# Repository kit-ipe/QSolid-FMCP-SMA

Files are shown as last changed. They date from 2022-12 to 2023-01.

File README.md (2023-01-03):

# FMC+ SMA

## Cloning the repository
- Libraries used in the project are in this other [cern repository](https://gitlab.cern.ch/p2-xware/hardware/kicad-pcbs/kit-kicad-library) or [kit repository](https://git.scc.kit.edu/cms-tt/hardware/kicad-pcbs/kit-kicad-library) and need to be linked using an **Environment Variable** inside KiCad (Preferences -> Configure Paths... ->) right after opening the project
 
  `KICAD_USER_LIBRARY = /path/to/KIT_KiCad_Library`

## 3D Views

### Top

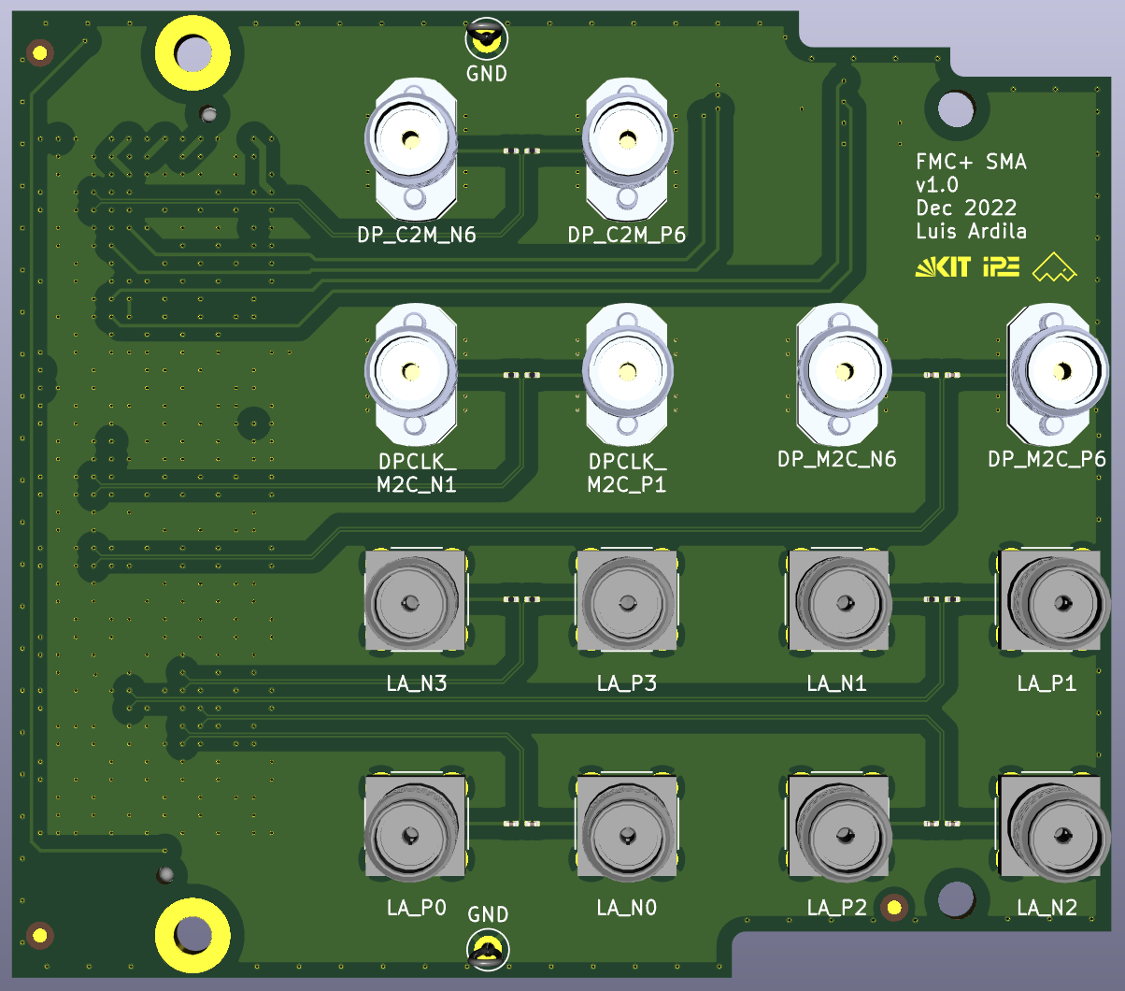
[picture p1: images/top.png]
Top View 3D


### Bottom

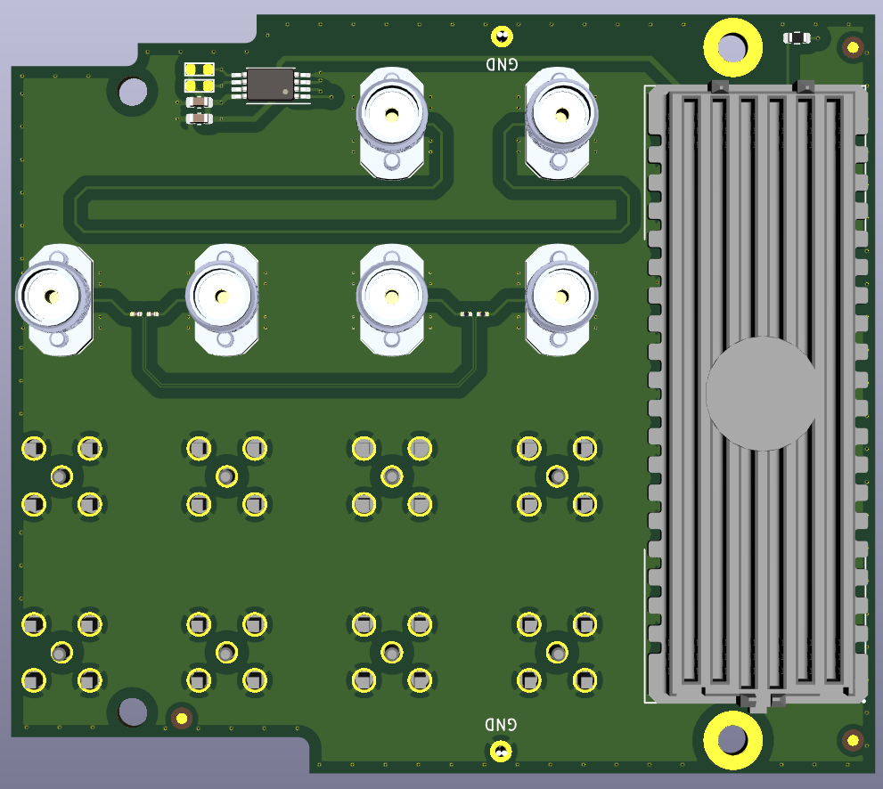
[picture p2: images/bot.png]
Bottom View 3D


## LICENSE

Copyright Luis Ardila, Marvin Fuchs, Robert Gartmann, Lukas Scheller 2023.

This source describes Open Hardware and is licensed under the CERN-OHL-P v2
You may redistribute and modify this documentation and make products
using it under the terms of the CERN-OHL-P v2 [https:/cern.ch/cern-ohl](https:/cern.ch/cern-ohl).
This documentation is distributed WITHOUT ANY EXPRESS OR IMPLIED
WARRANTY, INCLUDING OF MERCHANTABILITY, SATISFACTORY QUALITY
AND FITNESS FOR A PARTICULAR PURPOSE. Please see the CERN-OHL-P v2
for applicable conditions.

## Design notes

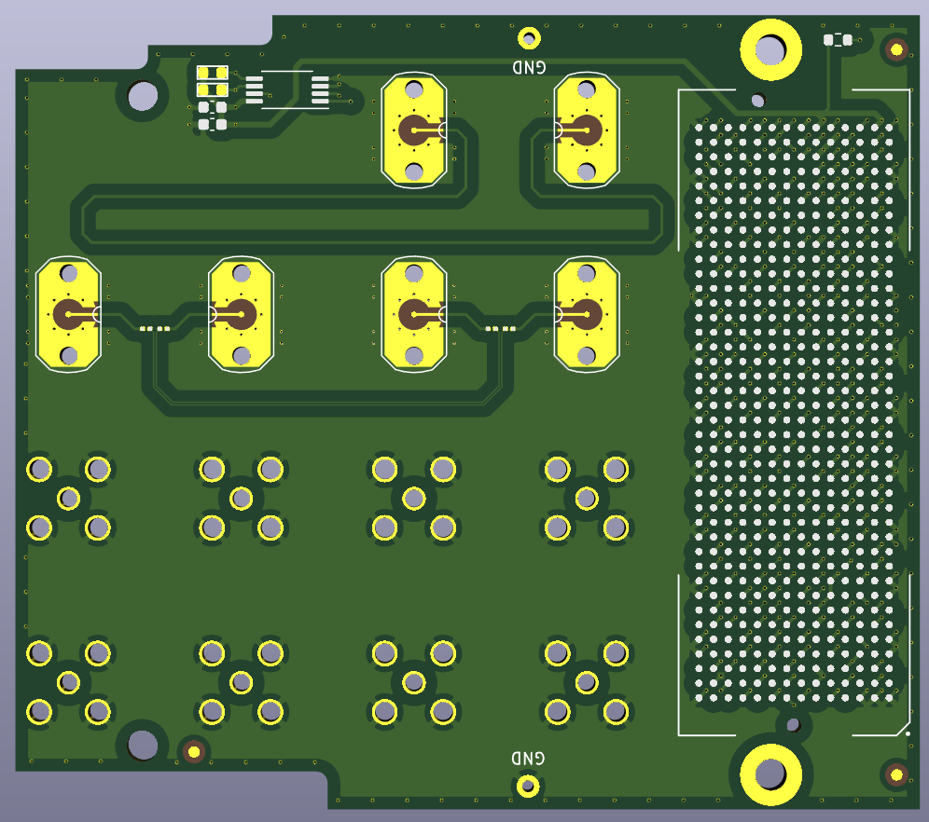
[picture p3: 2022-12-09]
images/bot-pcb.png

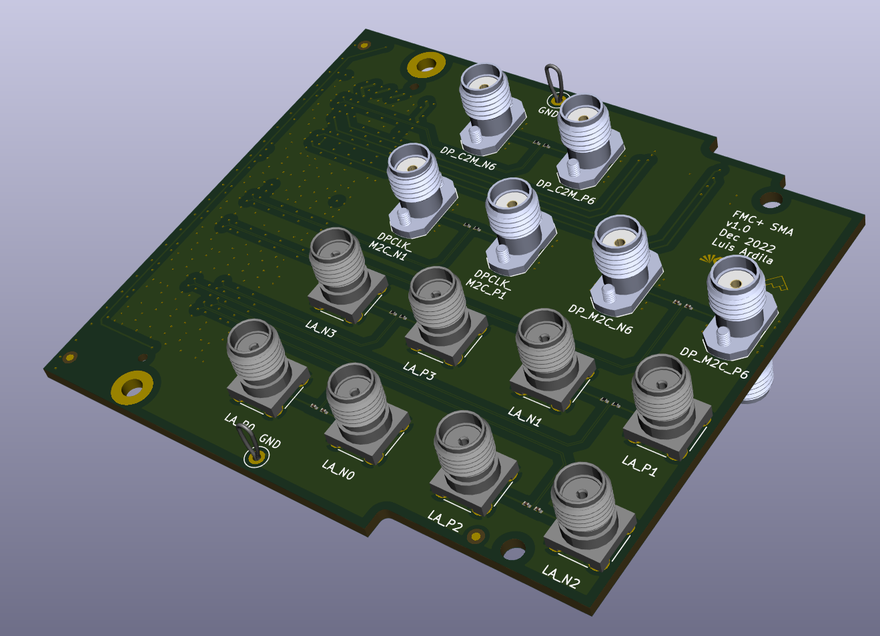
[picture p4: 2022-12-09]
images/iso.png

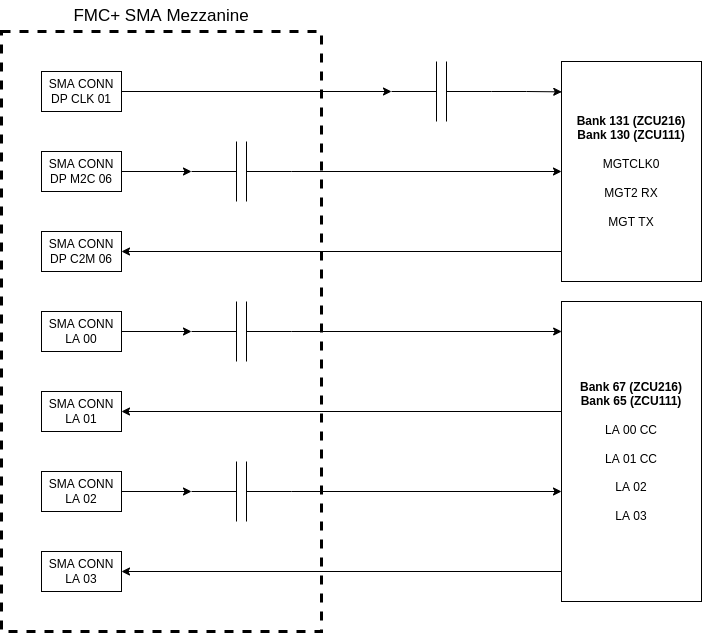
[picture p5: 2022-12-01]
images/fmcp_sma_block_diagram.drawio.png

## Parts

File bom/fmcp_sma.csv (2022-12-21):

refs | qty | Value | Footprint | Datasheet | rs# | info | stock | DNP | manf | manf#
C101 C102 C103 C104 C105 C106 C107 C108 | 8 | 0.1uF | Capacitor_SMD:C_0201_0603Metric | ~ | 185-1596 | 0201, 25V, X5R, 10% | Luis
C109 | 1 | 1uF | Capacitor_SMD:C_0603_1608Metric | ~ |  | 0402, 16V | AVT-IPE
C118 | 1 | 0.1uF | Capacitor_SMD:C_0603_1608Metric | ~ |  | 0402, 16V | AVT-IPE
FID101 FID102 FID103 FID104 FID105 FID106 | 6 | Fiducial | Fiducial:Fiducial_1mm_Mask2mm | ~
G101 | 1 | LA_LOGO | KIT_Graphic:LA_LOGO_MASK_NoName
G102 | 1 | KIT_LOGO | KIT_Graphic:KIT_LOGO_MASK_4.1x1.6mm
H102 H104 | 2 | M2.5 | MountingHole:MountingHole_2.7mm_M2.5 | ~
H101 H103 | 2 | M2.5_Pad | MountingHole:MountingHole_2.7mm_M2.5_Pad | ~
J101 J102 J104 J105 J106 J107 J116 J117 J118 J119 J120 J121 | 12 | Conn_Coaxial | KIT_Connector:SF2921-61345-1S | ~
J103 | 1 | FMCP_VITA57.4 | KIT_Connector:FMC_SEAM_ASP_184330_BGA-560_40x14_55.778x19.76mm | http://suddendocs.samtec.com/prints/asp-188588-01-mkt.pdf
J108 J109 J110 J111 J112 J113 J114 J115 | 8 | Conn_Coaxial | Connector_Coaxial:SMA_Amphenol_132134_Vertical | ~ | 253-0085 |  |  |  | Amphenol RF | 132134RP
J122 | 1 | Conn_01x03_Male | Connector_PinHeader_2.54mm:PinHeader_1x03_P2.54mm_Vertical | ~
R101 R102 R103 R104 R105 R106 R107 R108 R109 R112 | 10 | 0 | Resistor_SMD:R_0201_0603Metric | ~ |  |  | AVT-IPE
R110 R111 | 2 | 4.7k | KIT_Resistor_SMD:R_0603_1608Metric_DNP | ~ |  |  | AVT-IPE | DNP
R113 | 1 | 4.7k | Resistor_SMD:R_0603_1608Metric | ~ |  |  | AVT-IPE
TP101 TP102 TP104 TP105 | 4 | TestPoint | TestPoint:TestPoint_Loop_D2.50mm_Drill1.0mm | ~ | 262-2034
U101 | 1 | M24C02-FDW | Package_SO:TSSOP-8_4.4x3mm_P0.65mm | http://www.st.com/content/ccc/resource/technical/document/datasheet/b0/d8/50/40/5a/85/49/6f/DM00071904.pdf/files/DM00071904.pdf/jcr:content/translations/en.DM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 | 190-7599 |  |  |  | STMicroelectronics | M24C02-FDW6TP

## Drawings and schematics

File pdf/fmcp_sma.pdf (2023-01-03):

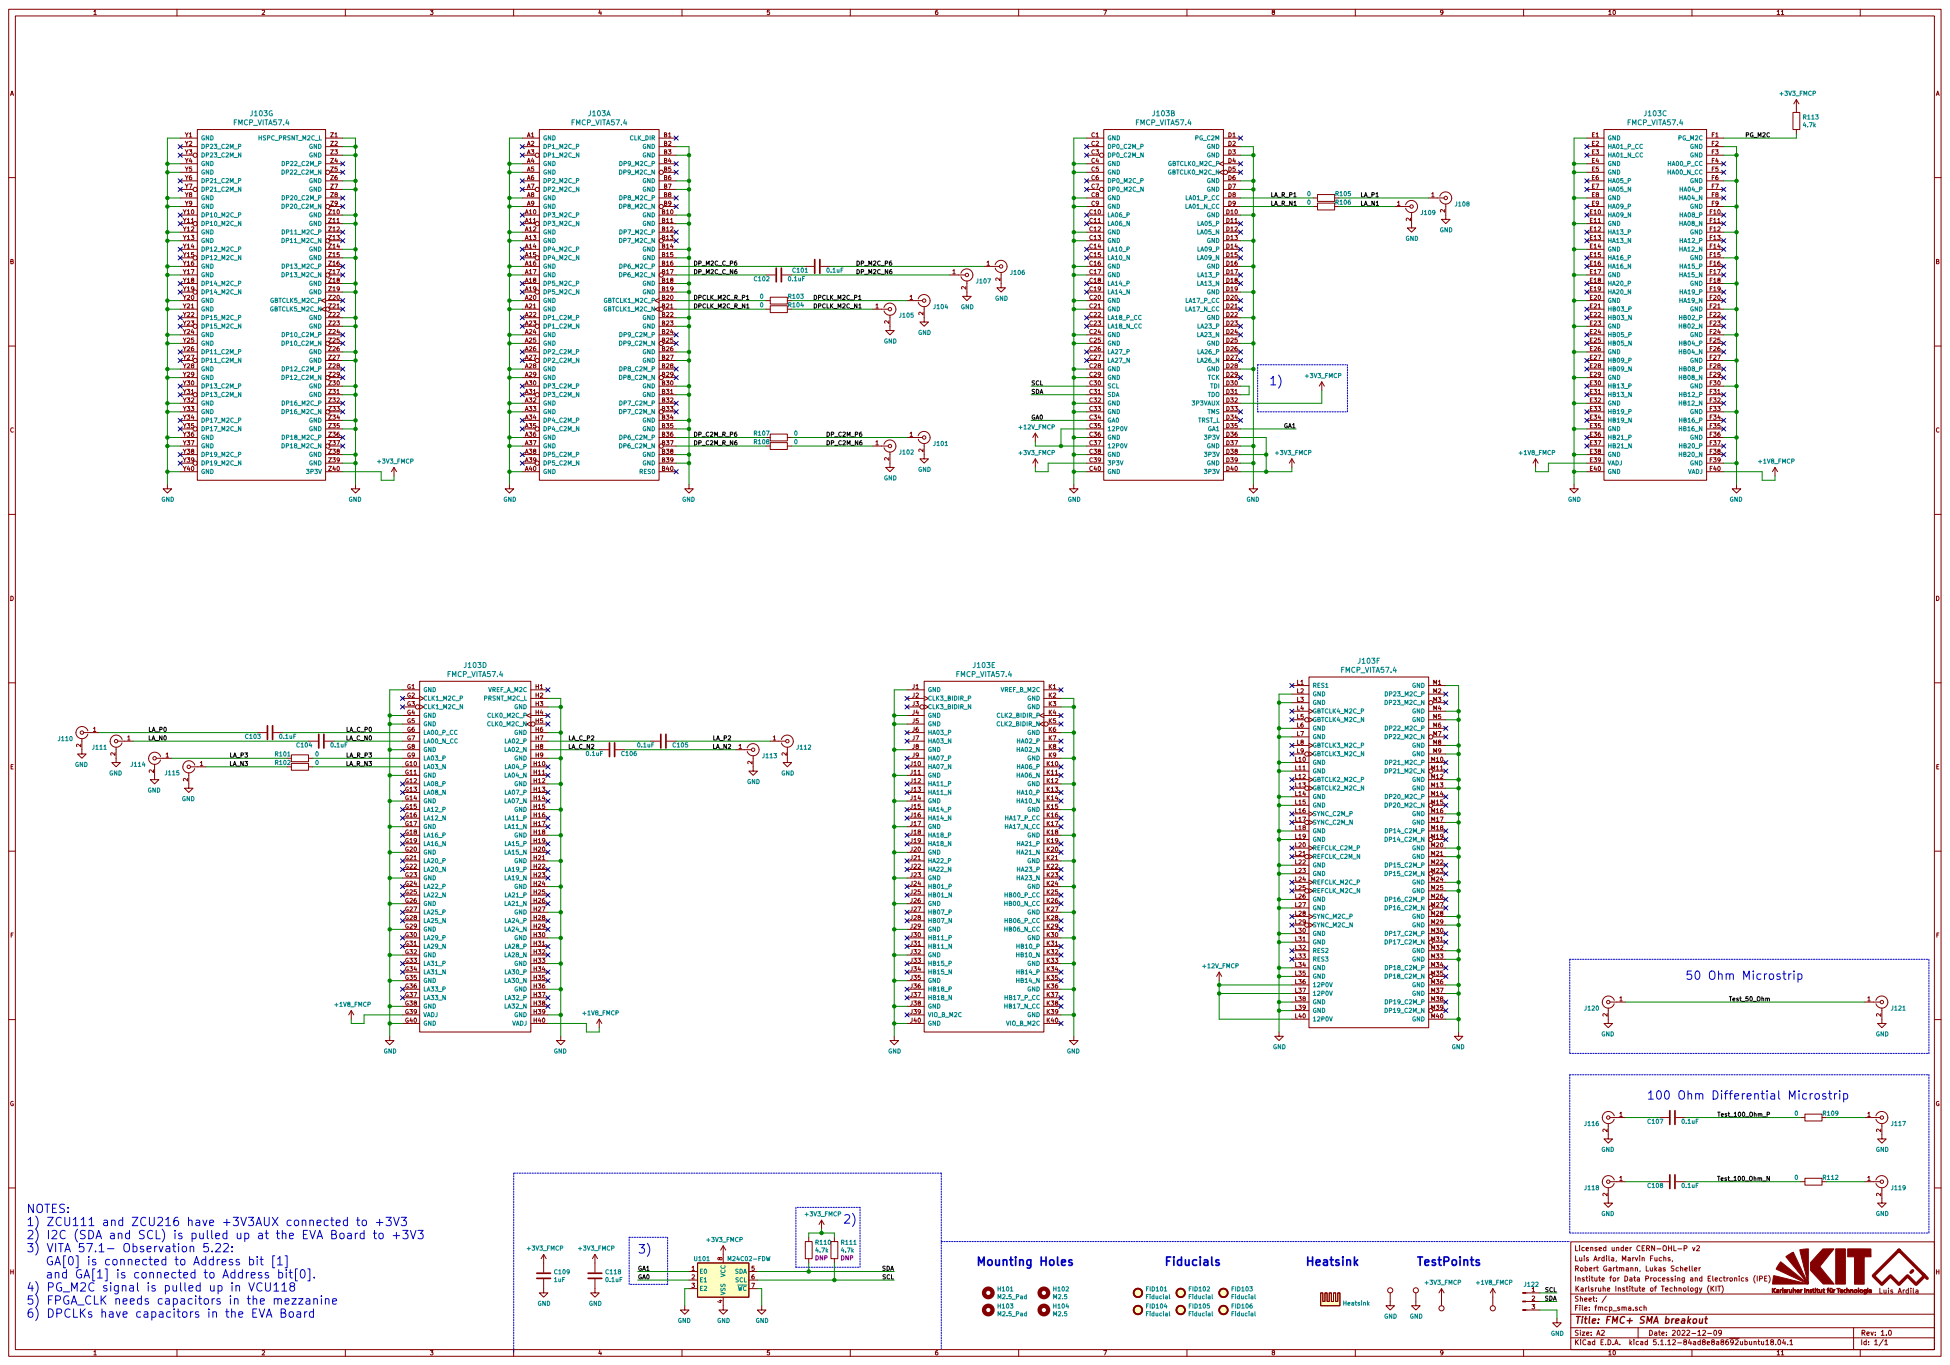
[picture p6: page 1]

NOTES:
1) ZCU111 and ZCU216 have +3V3AUX connected to +3V3
2) I2C (SDA and SCL) is pulled up at the EVA Board to +3V3
3) VITA 57.1- Observation 5.22:
GA[0] is connected to Address bit [1]
and GA[1] is connected to Address bit[0].
4) PG_M2C signal is pulled up in VCU118
5) FPGA_CLK needs capacitors in the mezzanine
6) DPCLKs have capacitors in the EVA Board

Luis Ardila, Marvin Fuchs, Licensed under CERN-OHL-P v2

4 SDA 5 SCL 6 WC 7 VCC

Robert Gartmann, Lukas Scheller
Institute for Data Processing and Electronics (IPE)
File: fmcp_sma.sch Sheet: / Karlsruhe Institute of Technology (KIT)

Id: 1/1 Title: FMC+ SMA breakout

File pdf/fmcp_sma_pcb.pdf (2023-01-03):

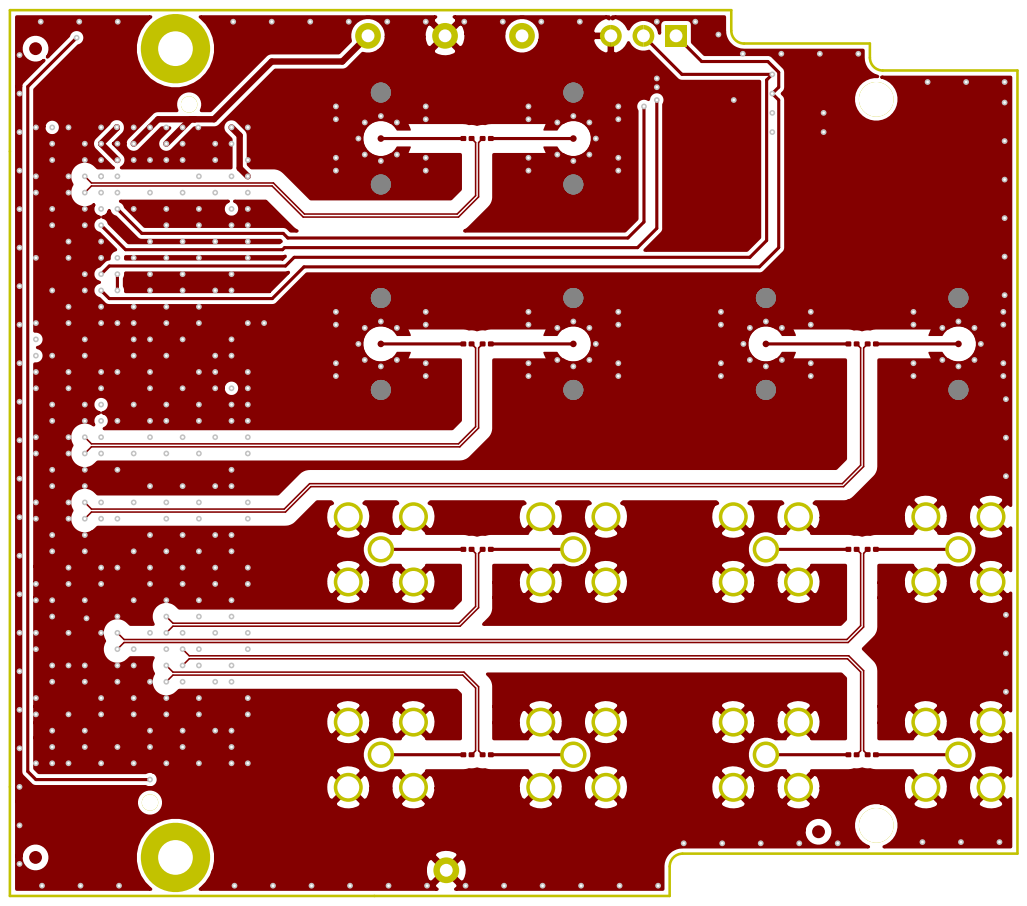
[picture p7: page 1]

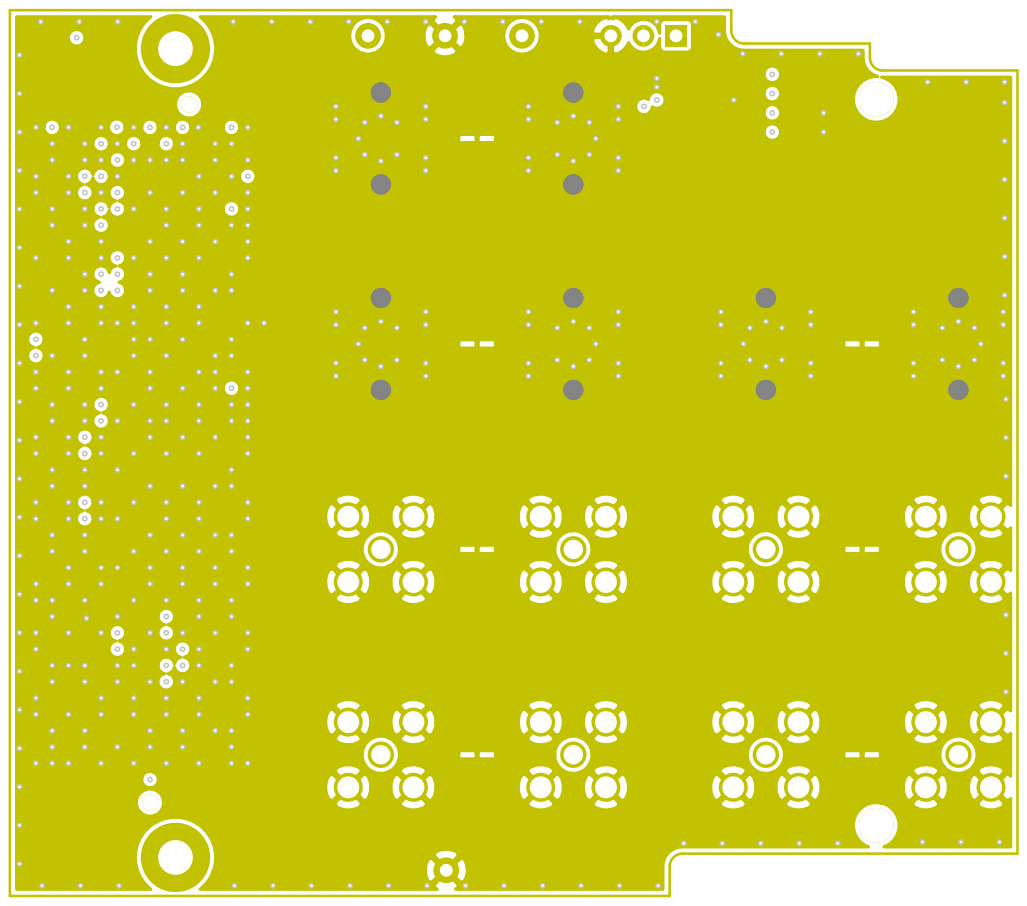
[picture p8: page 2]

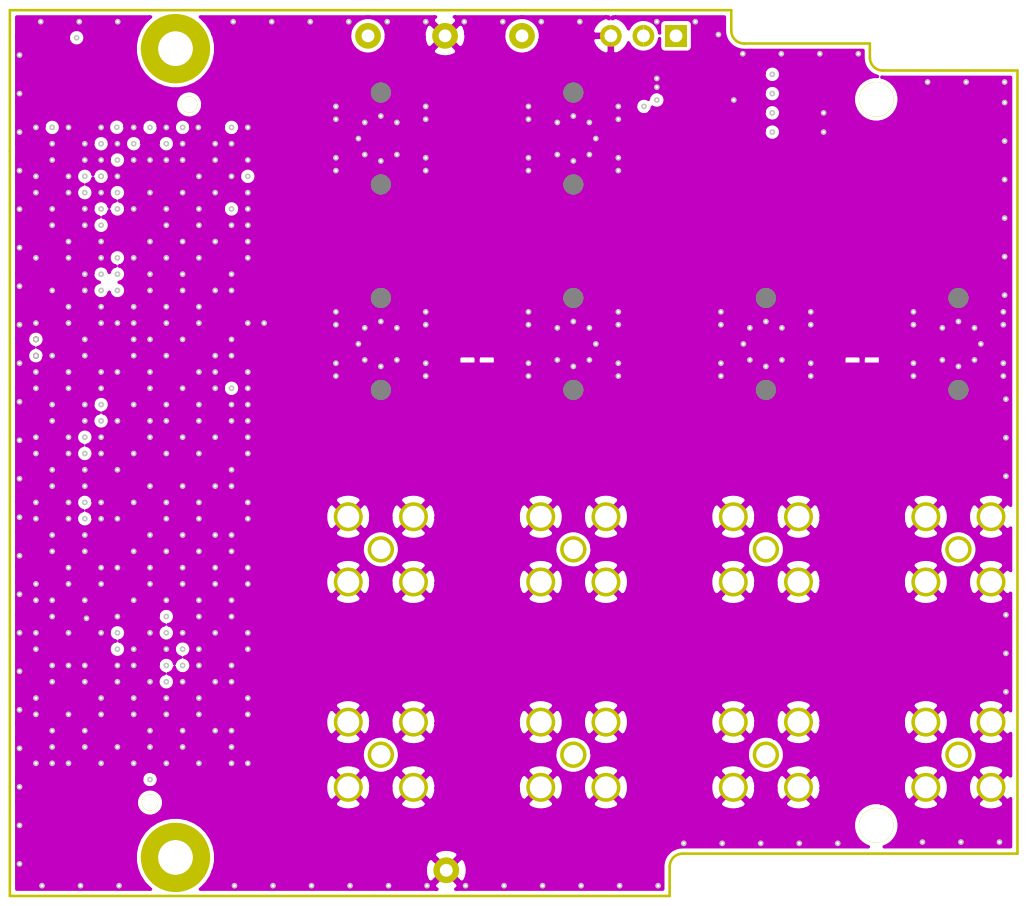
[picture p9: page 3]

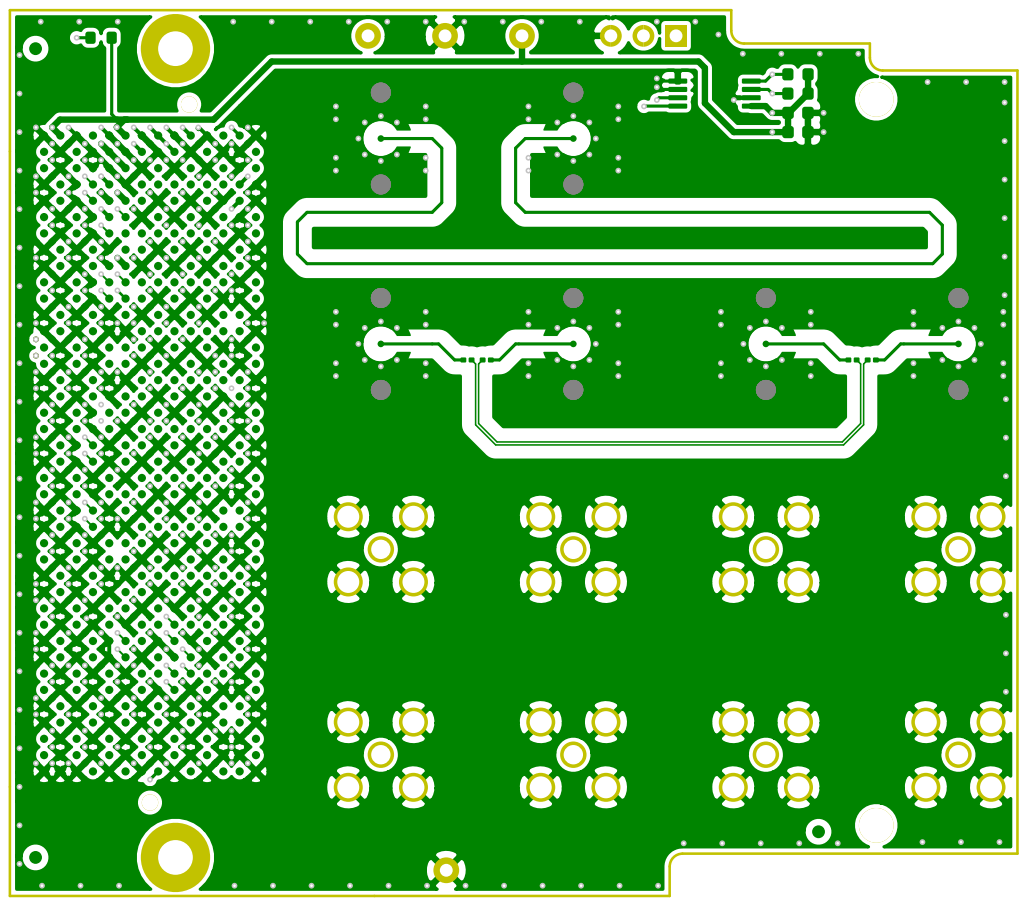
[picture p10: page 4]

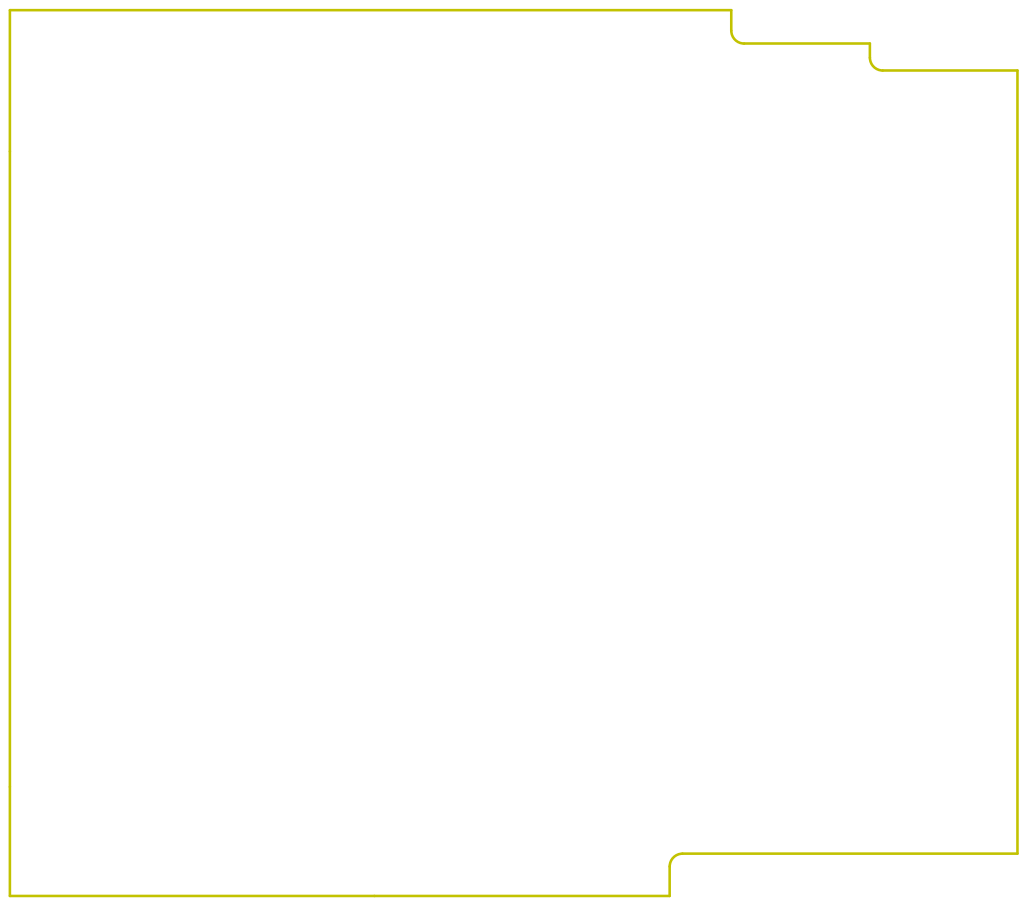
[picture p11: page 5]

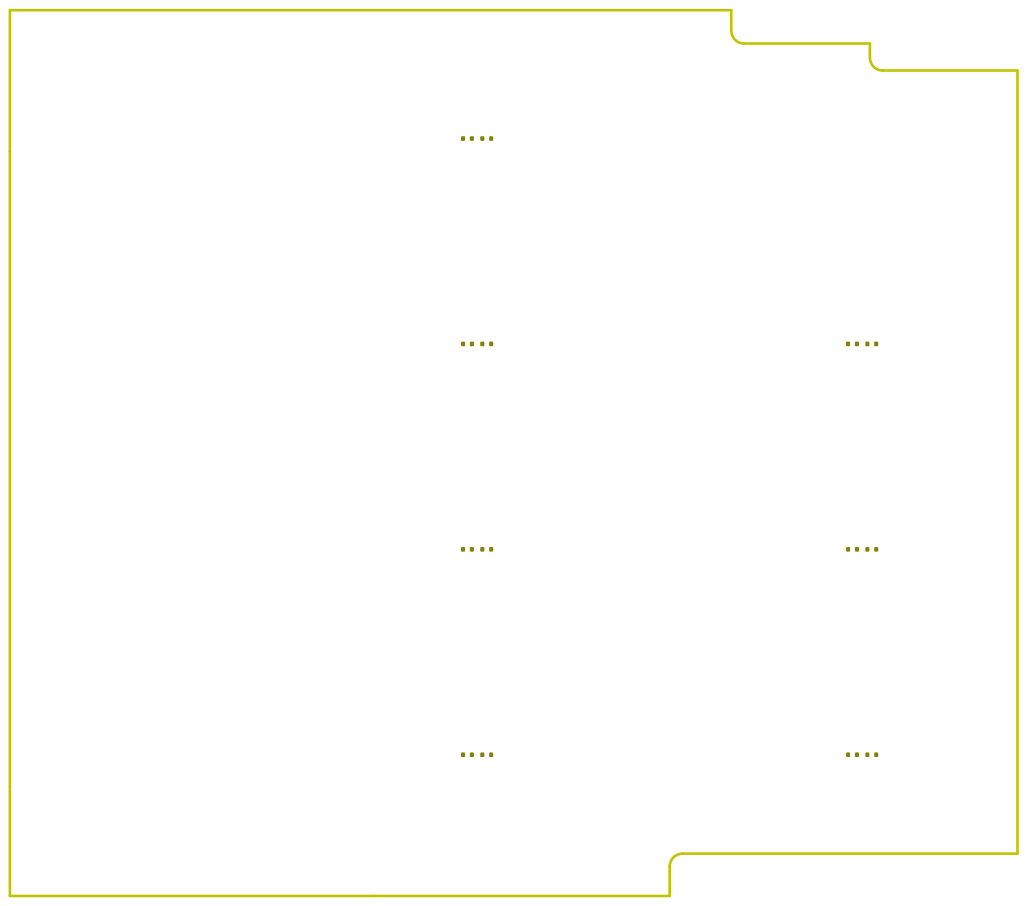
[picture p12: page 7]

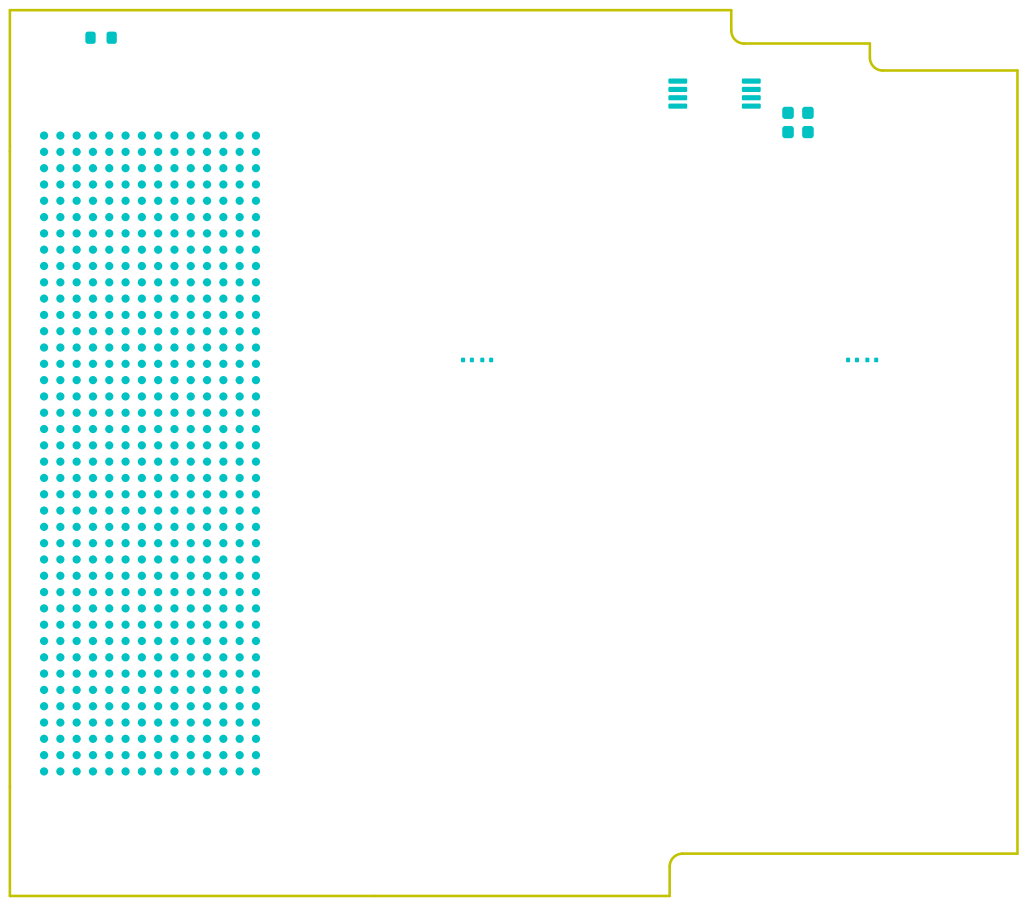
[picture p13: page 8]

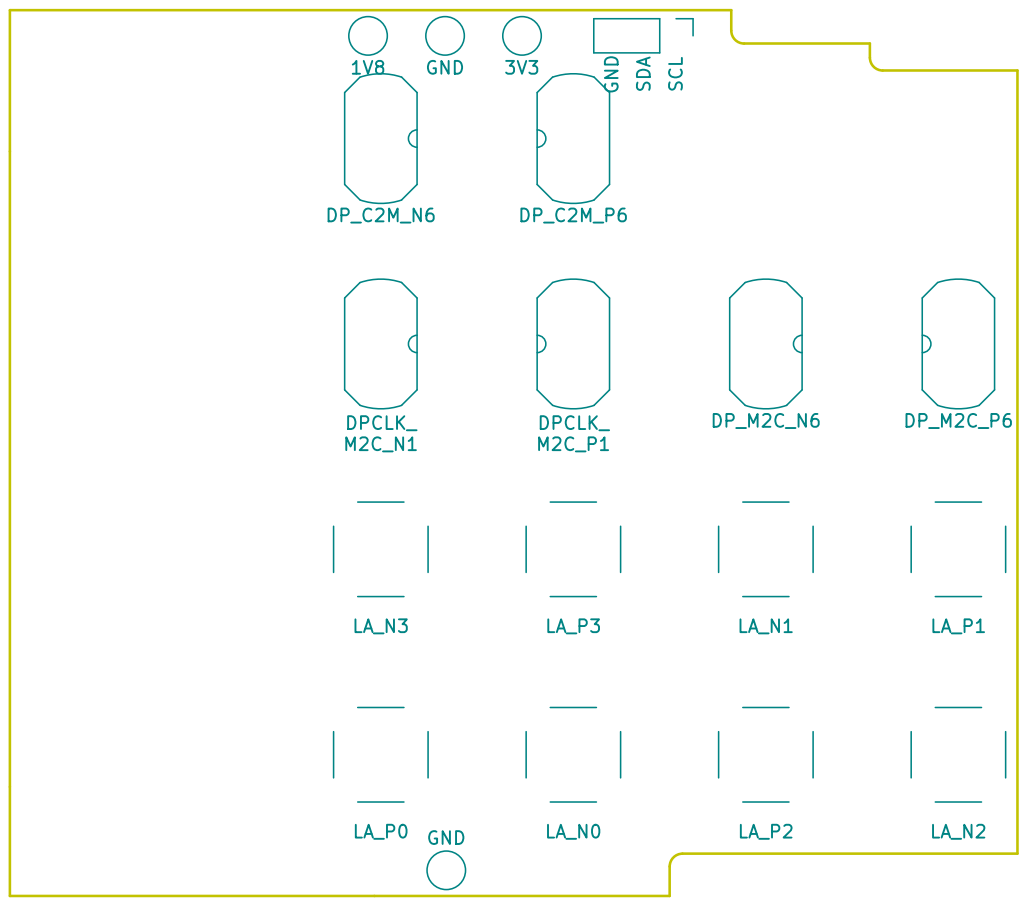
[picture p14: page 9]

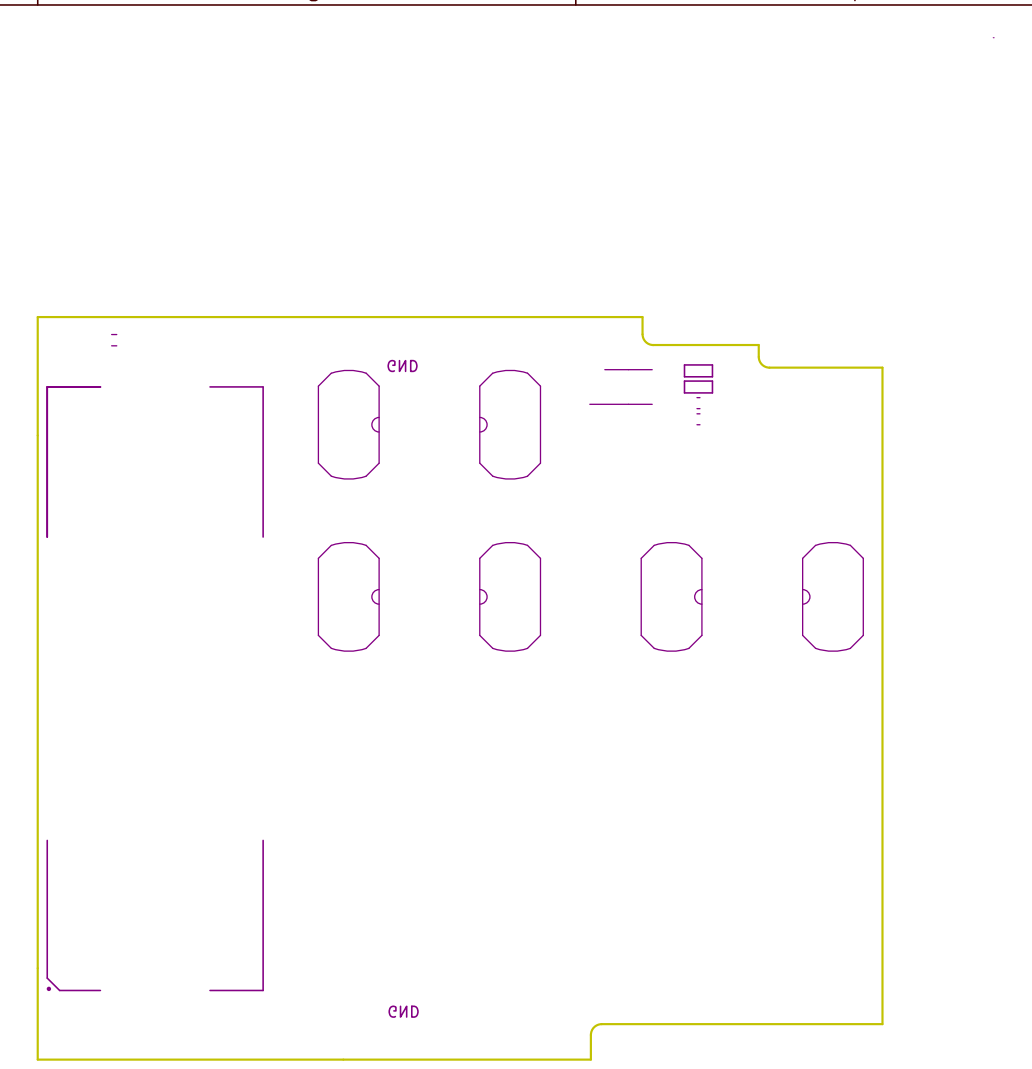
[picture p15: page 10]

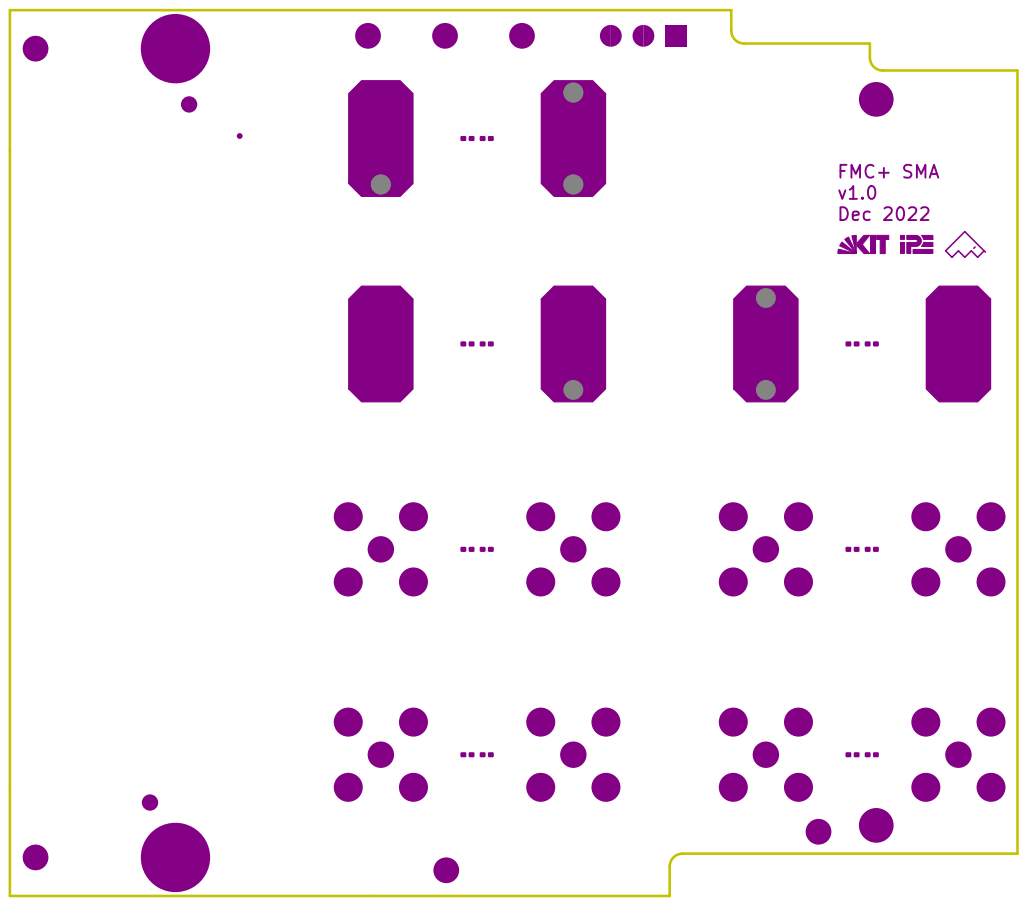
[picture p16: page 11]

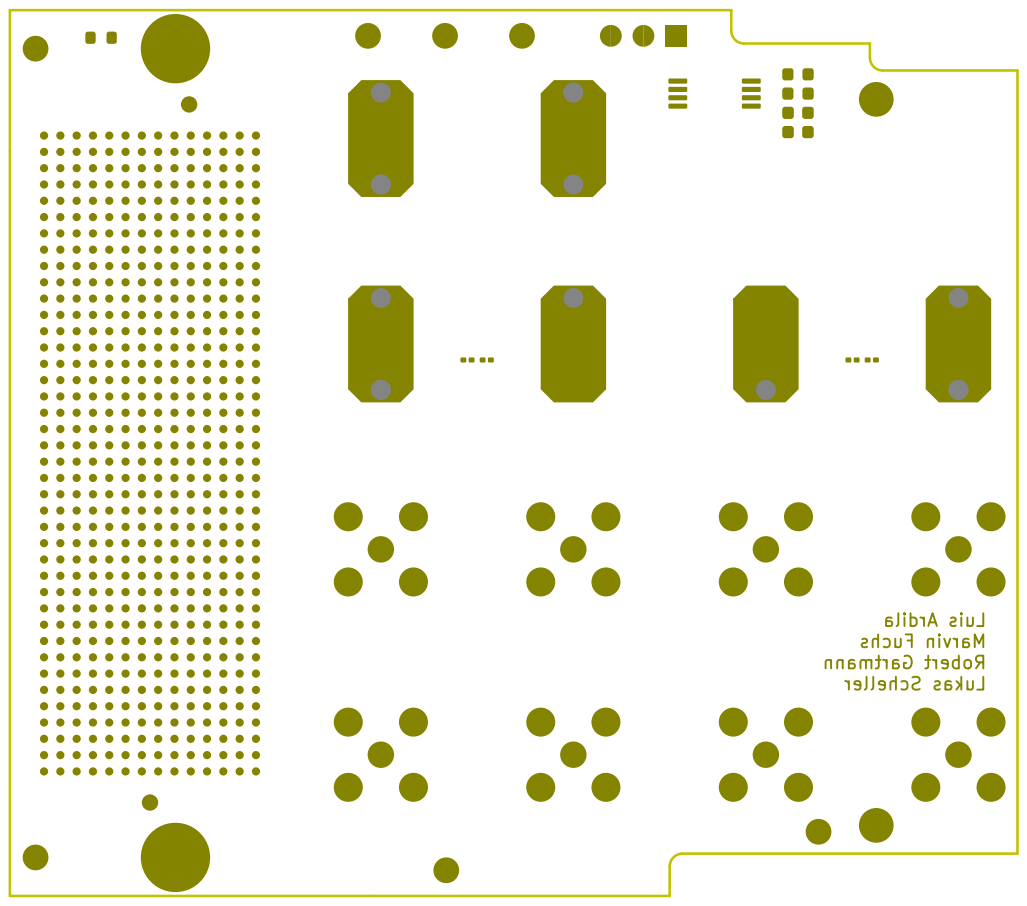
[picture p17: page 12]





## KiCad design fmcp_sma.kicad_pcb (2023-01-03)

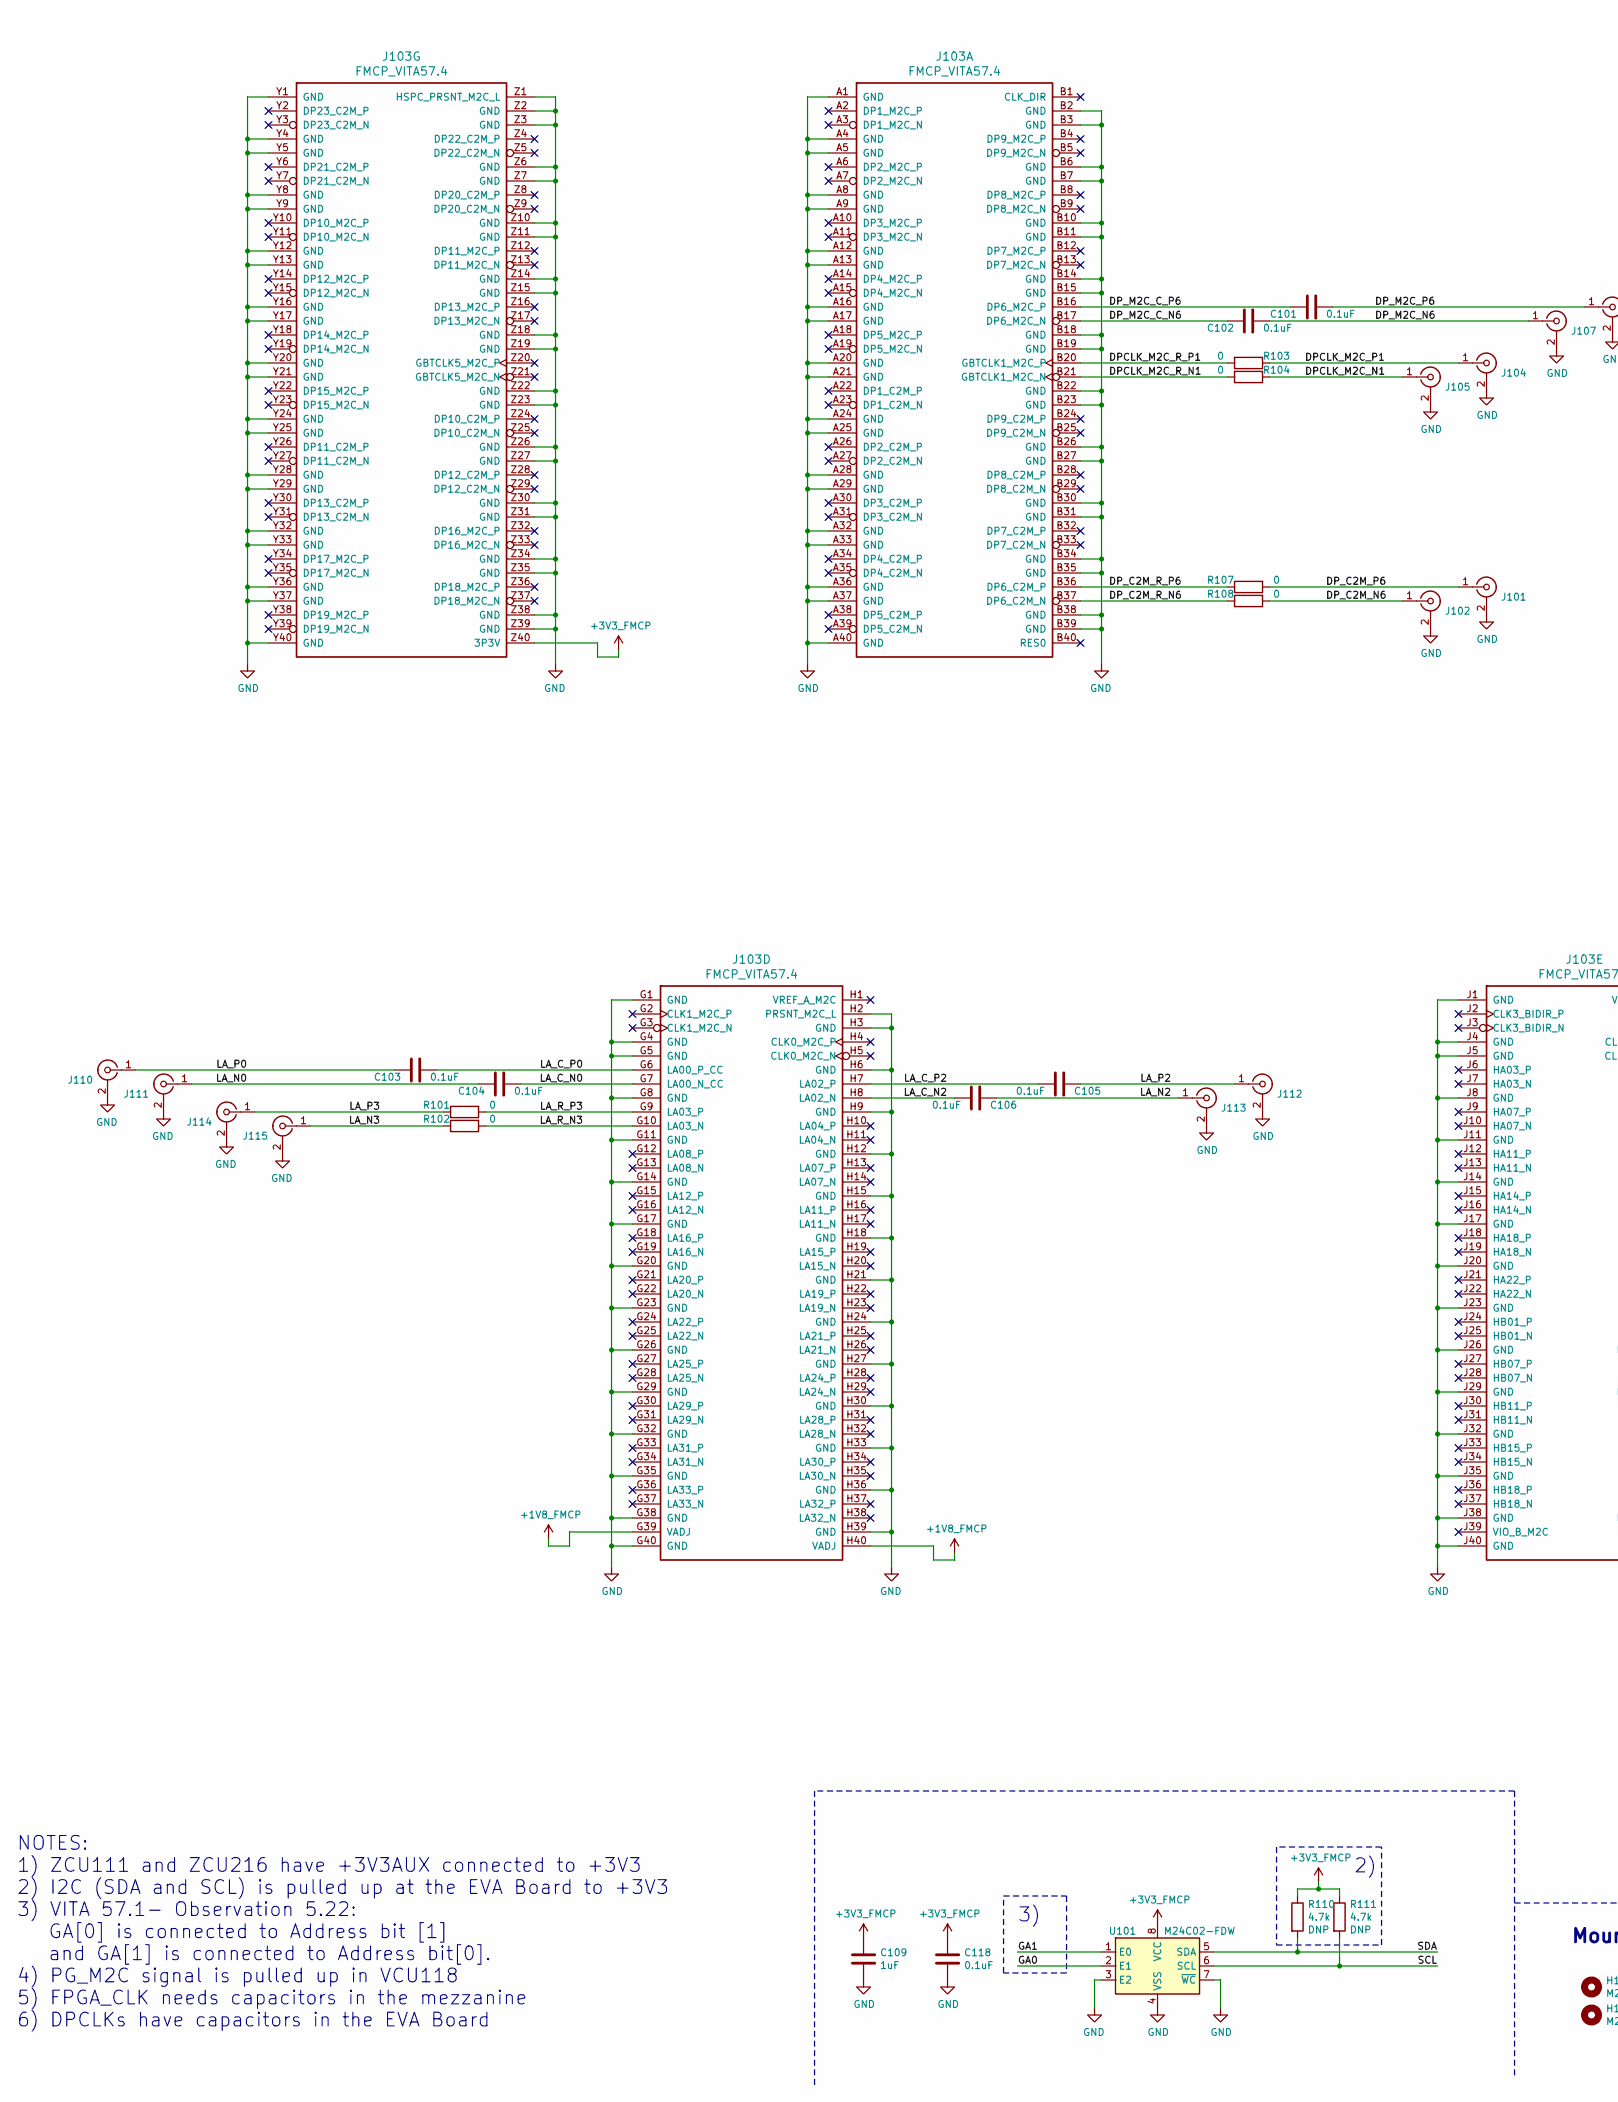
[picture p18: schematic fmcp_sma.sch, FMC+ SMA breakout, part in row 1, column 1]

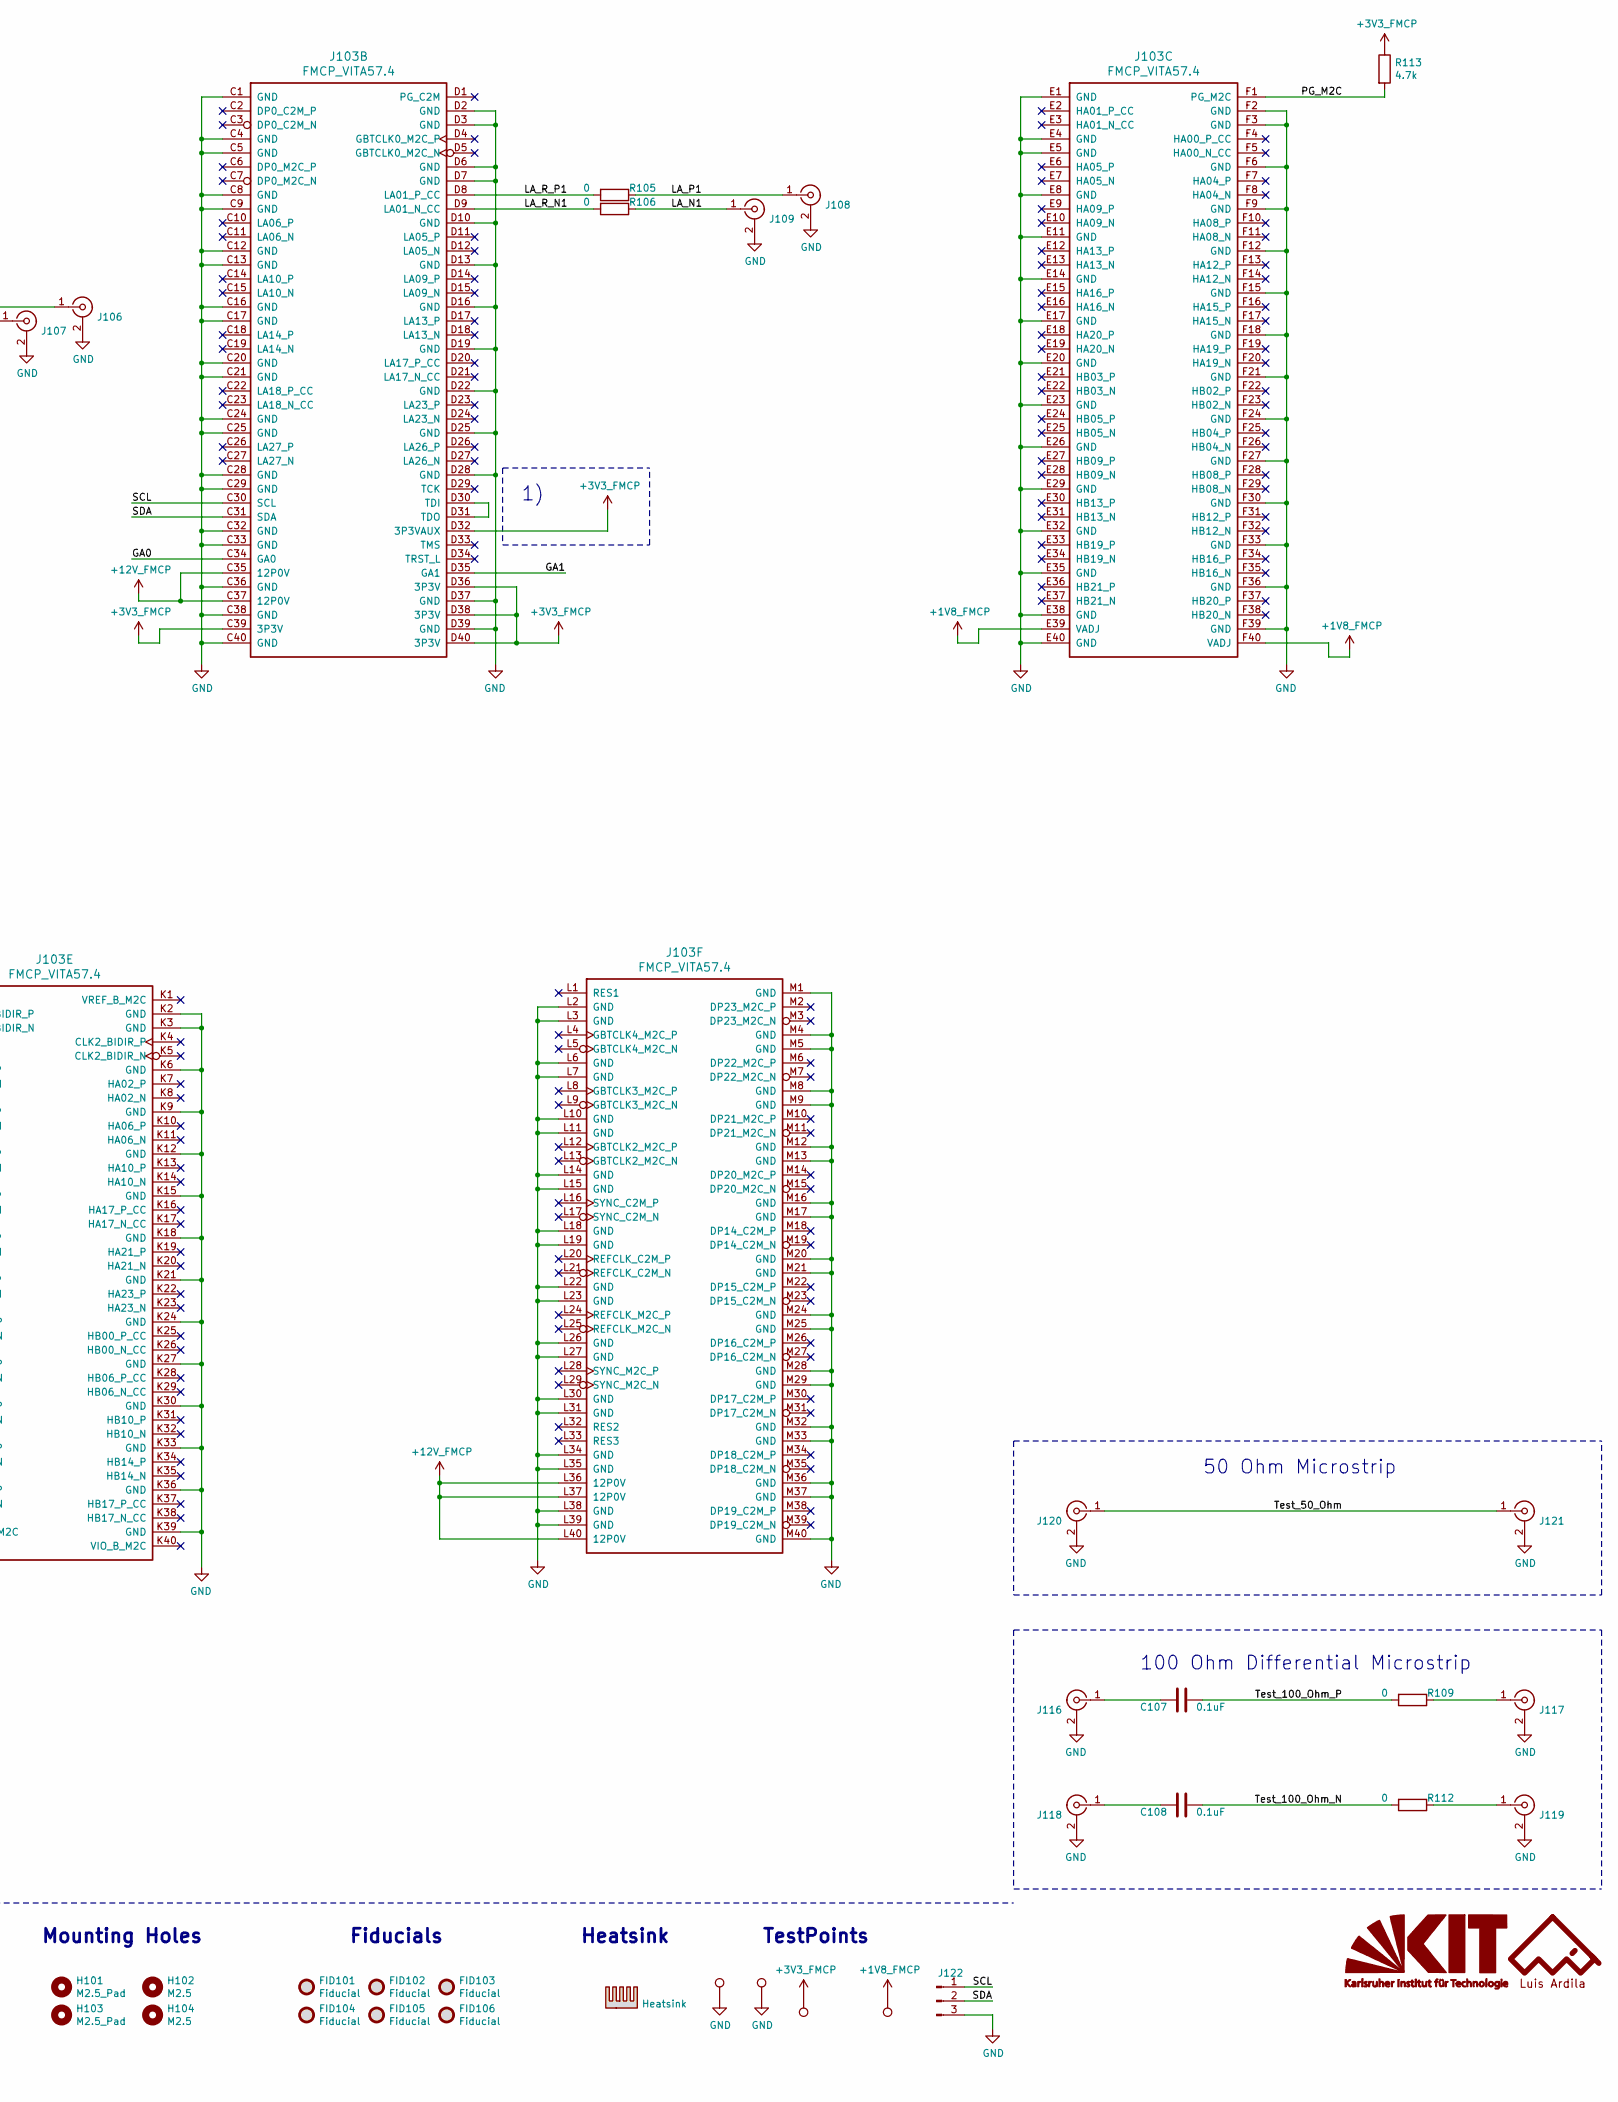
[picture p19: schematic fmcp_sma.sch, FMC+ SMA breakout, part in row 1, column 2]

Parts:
C101, C102, C103, C104, C105, C106, C107, C108: 0.1uF; C_0201_0603Metric
C109: 1uF; C_0603_1608Metric
C118: 0.1uF; C_0603_1608Metric
FID101, FID102, FID103, FID104, FID105, FID106: Fiducial; Fiducial_1mm_Mask2mm
G101: LA_LOGO; LA_LOGO_MASK_NoName
G102: KIT_LOGO; KIT_LOGO_MASK_4.1x1.6mm
H101, H103: M2.5_Pad; MountingHole_2.7mm_M2.5_Pad
H102, H104: M2.5; MountingHole_2.7mm_M2.5
J101, J102, J104, J105, J106, J107, J116, J117, J118, J119, J120, J121: Conn_Coaxial; SF2921-61345-1S
J103: FMCP_VITA57.4; FMC_SEAM_ASP_184330_BGA-560_40x14_55.778x19.76mm
J108, J109, J110, J111, J112, J113, J114, J115: Conn_Coaxial; SMA_Amphenol_132134_Vertical
J122: Conn_01x03_Male; PinHeader_1x03_P2.54mm_Vertical
R101, R102, R103, R104, R105, R106, R107, R108, R109, R112: 0; R_0201_0603Metric
R110, R111: 4.7k; R_0603_1608Metric_DNP
R113: 4.7k; R_0603_1608Metric
TP101, TP102, TP104, TP105: TestPoint; TestPoint_Loop_D2.50mm_Drill1.0mm
U101: M24C02-FDW; TSSOP-8_4.4x3mm_P0.65mm

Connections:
+1V8_FMCP: J103.E39 (VADJ), J103.F40 (VADJ), J103.G39 (VADJ), J103.H40 (VADJ), TP102.1
+3V3_FMCP: C109.1, C118.1, J103.C39 (3P3V), J103.D32 (3P3VAUX), J103.D36 (3P3V), J103.D38 (3P3V), J103.D40 (3P3V), J103.Z40 (3P3V), R110.1, R111.1, R113.1, TP101.1, U101.8 (VCC)
+12V_FMCP: J103.C35 (12P0V), J103.C37 (12P0V), J103.L36 (12P0V), J103.L37 (12P0V), J103.L40 (12P0V)
/DPCLK_M2C_N1: J105.1 (In), R104.1
/DPCLK_M2C_P1: J104.1 (In), R103.1
/DPCLK_M2C_R_N1: J103.B21 (GBTCLK1_M2C_N), R104.2
/DPCLK_M2C_R_P1: J103.B20 (GBTCLK1_M2C_P), R103.2
/DP_C2M_N6: J102.1 (In), R108.2
/DP_C2M_P6: J101.1 (In), R107.2
/DP_C2M_R_N6: J103.B37 (DP6_C2M_N), R108.1
/DP_C2M_R_P6: J103.B36 (DP6_C2M_P), R107.1
/DP_M2C_C_N6: C102.1, J103.B17 (DP6_M2C_N)
/DP_M2C_C_P6: C101.1, J103.B16 (DP6_M2C_P)
/DP_M2C_N6: C102.2, J107.1 (In)
/DP_M2C_P6: C101.2, J106.1 (In)
/GA0: J103.C34 (GA0), U101.2 (E1)
/GA1: J103.D35 (GA1), U101.1 (E0)
/LA_C_N0: C104.2, J103.G7 (LA00_N_CC)
/LA_C_N2: C106.2, J103.H8 (LA02_N)
/LA_C_P0: C103.2, J103.G6 (LA00_P_CC)
/LA_C_P2: C105.2, J103.H7 (LA02_P)
/LA_N0: C104.1, J111.1 (In)
/LA_N1: J109.1 (In), R106.1
/LA_N2: C106.1, J113.1 (In)
/LA_N3: J115.1 (In), R102.1
/LA_P0: C103.1, J110.1 (In)
/LA_P1: J108.1 (In), R105.1
/LA_P2: C105.1, J112.1 (In)
/LA_P3: J114.1 (In), R101.1
/LA_R_N1: J103.D9 (LA01_N_CC), R106.2
/LA_R_N3: J103.G10 (LA03_N), R102.2
/LA_R_P1: J103.D8 (LA01_P_CC), R105.2
/LA_R_P3: J103.G9 (LA03_P), R101.2
/PG_M2C: J103.F1 (PG_M2C), R113.2
/SCL: J103.C30 (SCL), J122.1, R111.2, U101.6 (SCL)
/SDA: J103.C31 (SDA), J122.2, R110.2, U101.5 (SDA)
/Test_50_Ohm: J120.1 (In), J121.1 (In)
/Test_100_Ohm_N: C108.2, R112.2
/Test_100_Ohm_P: C107.2, R109.2
GND: C109.2, C118.2, J101.2 (Ext), J102.2 (Ext), J103.A1 (GND), J103.A4 (GND), J103.A5 (GND), J103.A8 (GND), J103.A9 (GND), J103.A12 (GND), J103.A13 (GND), J103.A16 (GND), J103.A17 (GND), J103.A20 (GND), J103.A21 (GND), J103.A24 (GND), J103.A25 (GND), J103.A28 (GND), J103.A29 (GND), J103.A32 (GND), J103.A33 (GND), J103.A36 (GND), J103.A37 (GND), J103.A40 (GND), J103.B2 (GND), J103.B3 (GND), J103.B6 (GND), J103.B7 (GND), J103.B10 (GND), J103.B11 (GND), J103.B14 (GND), J103.B15 (GND), J103.B18 (GND), J103.B19 (GND), J103.B22 (GND), J103.B23 (GND), J103.B26 (GND), J103.B27 (GND), J103.B30 (GND), J103.B31 (GND), J103.B34 (GND), J103.B35 (GND), J103.B38 (GND), J103.B39 (GND), J103.C1 (GND), J103.C4 (GND), J103.C5 (GND), J103.C8 (GND), J103.C9 (GND), J103.C12 (GND), J103.C13 (GND), J103.C16 (GND), J103.C17 (GND), J103.C20 (GND), J103.C21 (GND), J103.C24 (GND), J103.C25 (GND), J103.C28 (GND), J103.C29 (GND), J103.C32 (GND), J103.C33 (GND), J103.C36 (GND), J103.C38 (GND), J103.C40 (GND), J103.D2 (GND), J103.D3 (GND), J103.D6 (GND), J103.D7 (GND), J103.D10 (GND), J103.D13 (GND), J103.D16 (GND), J103.D19 (GND), J103.D22 (GND), J103.D25 (GND), J103.D28 (GND), J103.D37 (GND), J103.D39 (GND), J103.E1 (GND), J103.E4 (GND), J103.E5 (GND), J103.E8 (GND), J103.E11 (GND), J103.E14 (GND), J103.E17 (GND), J103.E20 (GND), J103.E23 (GND), J103.E26 (GND), J103.E29 (GND), J103.E32 (GND), J103.E35 (GND), J103.E38 (GND), J103.E40 (GND), J103.F2 (GND), J103.F3 (GND), J103.F6 (GND), J103.F9 (GND), J103.F12 (GND), J103.F15 (GND), J103.F18 (GND), J103.F21 (GND), J103.F24 (GND), J103.F27 (GND), J103.F30 (GND), J103.F33 (GND), J103.F36 (GND), J103.F39 (GND), J103.G1 (GND), J103.G4 (GND), J103.G5 (GND), J103.G8 (GND), J103.G11 (GND), J103.G14 (GND), J103.G17 (GND), J103.G20 (GND), J103.G23 (GND), J103.G26 (GND), J103.G29 (GND), J103.G32 (GND), J103.G35 (GND), J103.G38 (GND), J103.G40 (GND), J103.H2 (PRSNT_M2C_L), J103.H3 (GND), J103.H6 (GND), J103.H9 (GND), J103.H12 (GND), J103.H15 (GND), J103.H18 (GND), J103.H21 (GND), J103.H24 (GND), J103.H27 (GND), J103.H30 (GND), J103.H33 (GND), J103.H36 (GND), J103.H39 (GND), J103.J1 (GND), J103.J4 (GND), J103.J5 (GND), J103.J8 (GND), J103.J11 (GND), J103.J14 (GND), J103.J17 (GND), J103.J20 (GND), J103.J23 (GND), J103.J26 (GND), J103.J29 (GND), J103.J32 (GND), J103.J35 (GND), J103.J38 (GND), J103.J40 (GND), J103.K2 (GND), J103.K3 (GND), J103.K6 (GND), J103.K9 (GND), J103.K12 (GND), J103.K15 (GND), J103.K18 (GND), J103.K21 (GND), J103.K24 (GND), J103.K27 (GND), J103.K30 (GND), J103.K33 (GND), J103.K36 (GND), J103.K39 (GND), J103.L2 (GND), J103.L3 (GND), J103.L6 (GND), J103.L7 (GND), J103.L10 (GND), J103.L11 (GND), J103.L14 (GND), J103.L15 (GND), J103.L18 (GND), J103.L19 (GND), J103.L22 (GND), J103.L23 (GND), J103.L26 (GND), J103.L27 (GND), J103.L30 (GND), J103.L31 (GND), J103.L34 (GND), J103.L35 (GND), J103.L38 (GND), J103.L39 (GND), J103.M1 (GND), J103.M4 (GND), J103.M5 (GND), J103.M8 (GND), J103.M9 (GND), J103.M12 (GND), J103.M13 (GND), J103.M16 (GND), J103.M17 (GND), J103.M20 (GND), J103.M21 (GND), J103.M24 (GND), J103.M25 (GND), J103.M28 (GND), J103.M29 (GND), J103.M32 (GND), J103.M33 (GND), J103.M36 (GND), J103.M37 (GND), J103.M40 (GND), J103.Y1 (GND), J103.Y4 (GND), J103.Y5 (GND), J103.Y8 (GND), J103.Y9 (GND), J103.Y12 (GND), J103.Y13 (GND), J103.Y16 (GND), J103.Y17 (GND), J103.Y20 (GND), J103.Y21 (GND), J103.Y24 (GND), J103.Y25 (GND), J103.Y28 (GND), J103.Y29 (GND), J103.Y32 (GND), J103.Y33 (GND), J103.Y36 (GND), J103.Y37 (GND), J103.Y40 (GND), J103.Z1 (HSPC_PRSNT_M2C_L), J103.Z2 (GND), J103.Z3 (GND), J103.Z6 (GND), J103.Z7 (GND), J103.Z10 (GND), J103.Z11 (GND), J103.Z14 (GND), J103.Z15 (GND), J103.Z18 (GND), J103.Z19 (GND), J103.Z22 (GND), J103.Z23 (GND), J103.Z26 (GND), J103.Z27 (GND), J103.Z30 (GND), J103.Z31 (GND), J103.Z34 (GND), J103.Z35 (GND), J103.Z38 (GND), J103.Z39 (GND), J104.2 (Ext), J105.2 (Ext), J106.2 (Ext), J107.2 (Ext), J108.2 (Ext), J109.2 (Ext), J110.2 (Ext), J111.2 (Ext), J112.2 (Ext), J113.2 (Ext), J114.2 (Ext), J115.2 (Ext), J116.2 (Ext), J117.2 (Ext), J118.2 (Ext), J119.2 (Ext), J120.2 (Ext), J121.2 (Ext), J122.3, TP104.1, TP105.1, U101.3 (E2), U101.4 (VSS), U101.7 (~WC)
unnamed: C107.1, J116.1 (In)
unnamed: C108.1, J118.1 (In)
unnamed: J103.D30 (TDI), J103.D31 (TDO)
unnamed: J117.1 (In), R109.1
unnamed: J119.1 (In), R112.1

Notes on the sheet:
Mounting Holes
Fiducials
Heatsink
TestPoints
NOTES: 1) ZCU111 and ZCU216 have +3V3AUX connected to +3V3 2) I2C (SDA and SCL) is pulled up at the EVA Board to +3V3 3) VITA 57.1- Observation 5.22: GA[0] is connected to Address bit [1] and GA[1] is connected to Address bit[0]. 4) PG_M2C signal is pulled up in VCU118 5) FPGA_CLK needs capacitors 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
100 Ohm Differential Microstrip
50 Ohm Microstrip

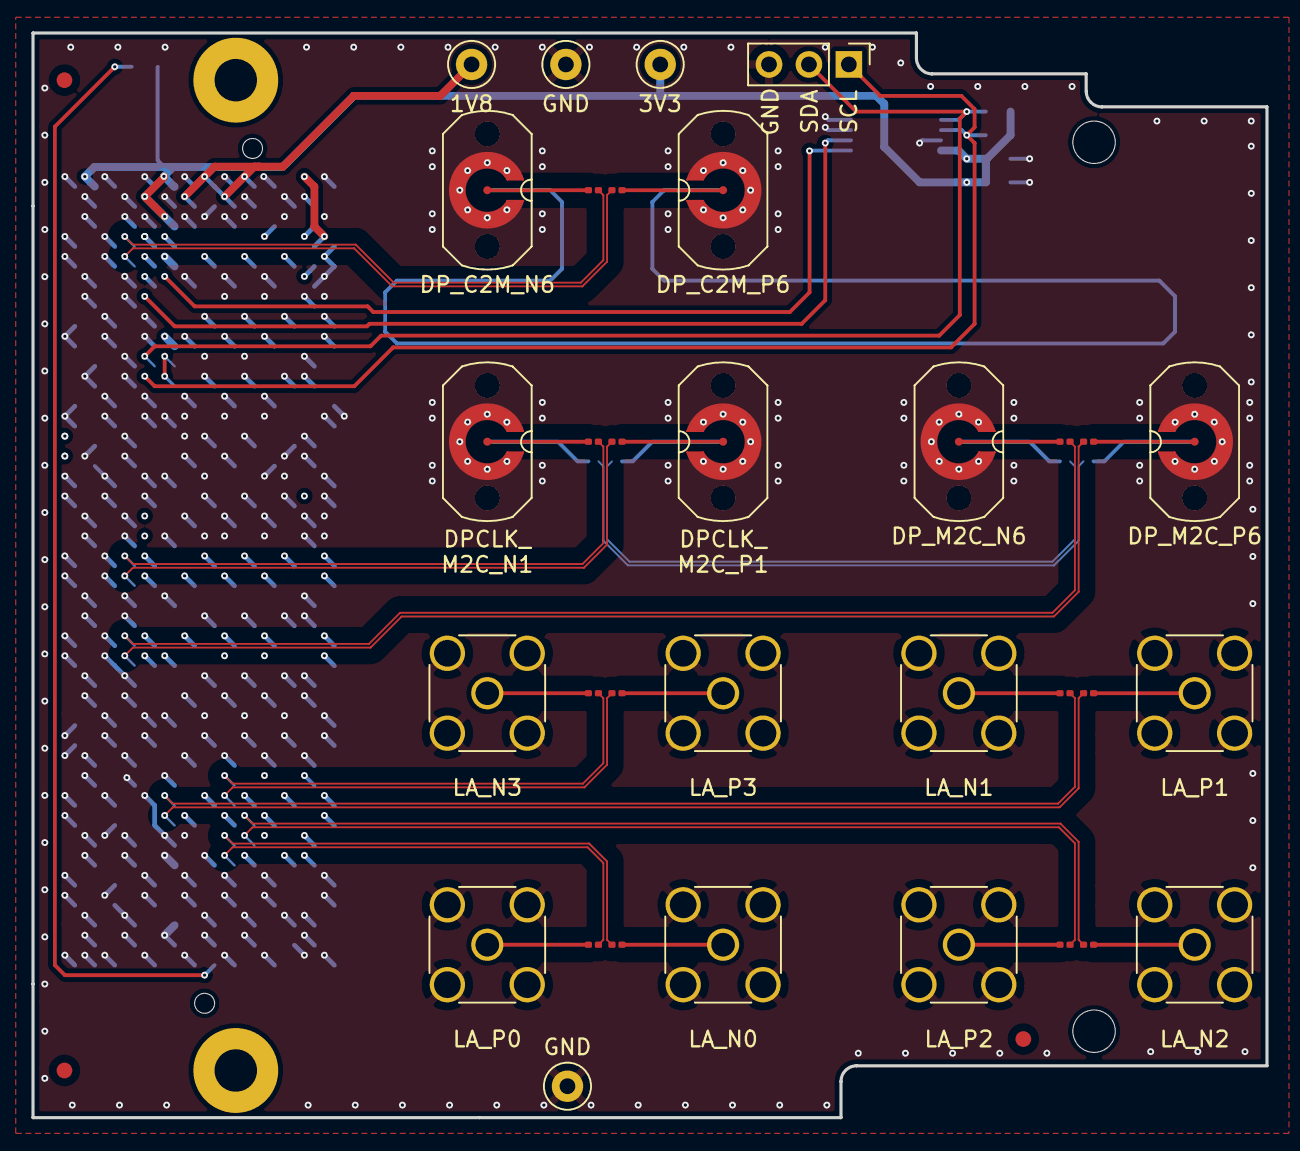
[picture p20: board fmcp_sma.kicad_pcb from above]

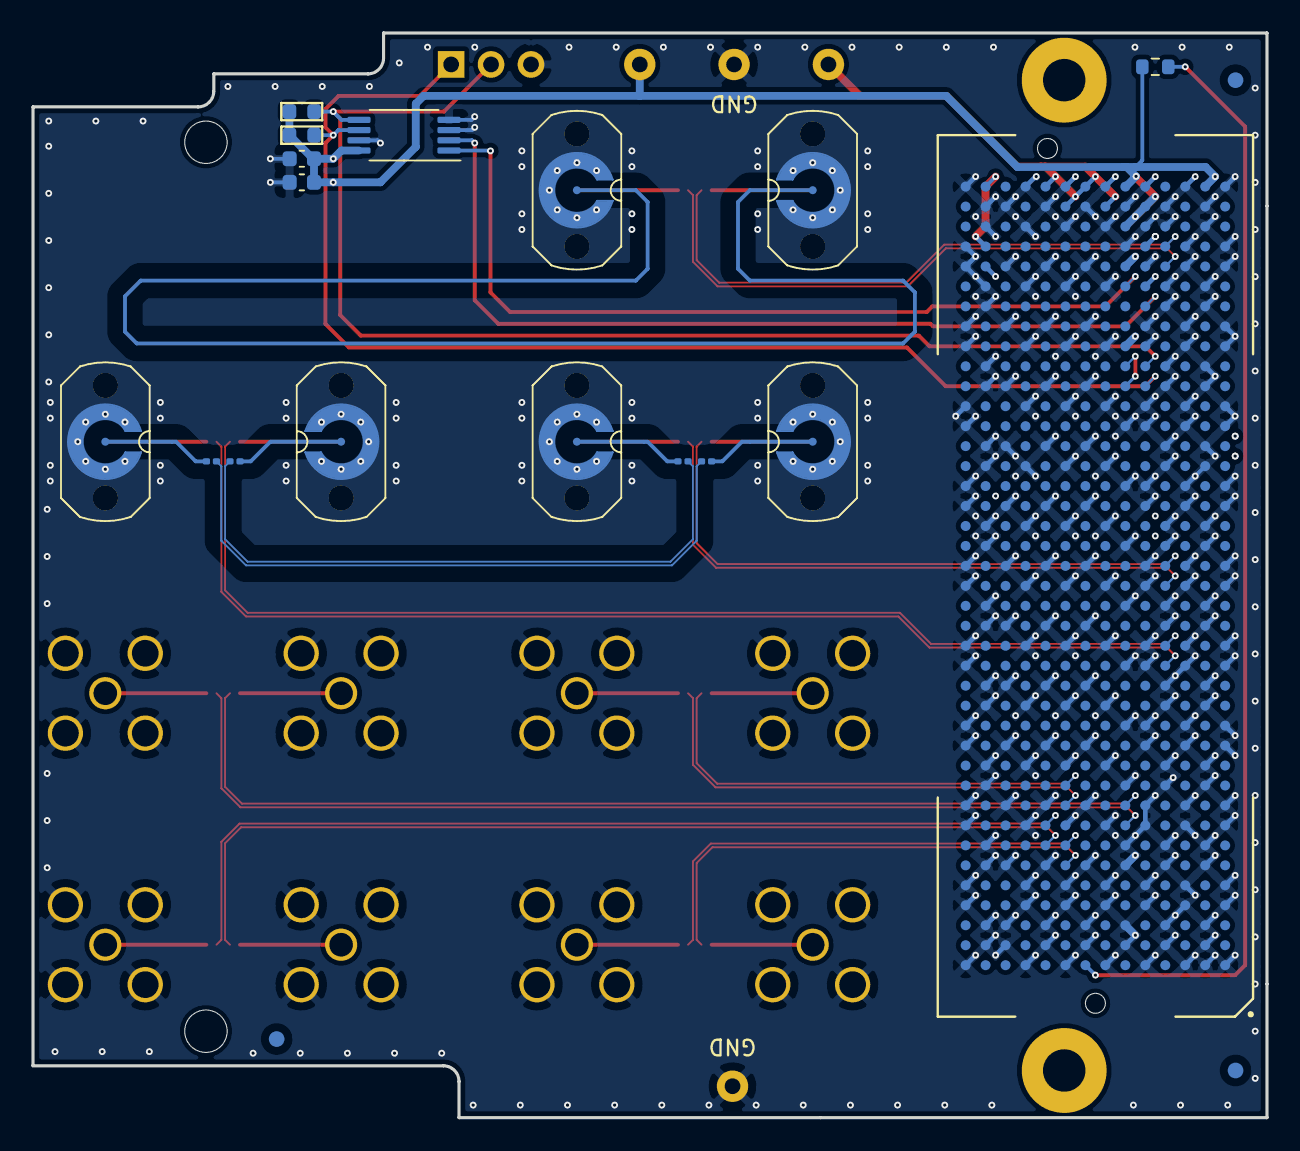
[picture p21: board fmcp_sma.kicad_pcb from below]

Board: 4 copper layers, 78.5 x 69.0 mm, 63 parts (20 on the bottom side), 45 nets.

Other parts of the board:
Board_Stackup-4Layer: Board_Stackup-4Layer; Board_Stackup-4Layer-Metric

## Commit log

2022-12-01 adding smas
    [fmcp_sma.sch]
2022-12-01 added pdf
    [fmcp_sma.sch]
2022-12-06 updated footprint
    [fmcp_sma.kicad_pcb, fmcp_sma.sch]
2022-12-09 modified footprint for screw on sma conn@
    [fmcp_sma-B_CrtYd.gbr, fmcp_sma-B_Cu.gbr, fmcp_sma-B_Mask.gbr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]
2022-12-09 re-pour zones with 0.3 clearance and 1mm for traces only
    [fmcp_sma-B_CrtYd.gbr, fmcp_sma-B_Cu.gbr, fmcp_sma-B_Mask.gbr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]
2022-12-12 updated gerbers
    [fmcp_sma-B_CrtYd.gbr, fmcp_sma-B_Cu.gbr, fmcp_sma-B_Mask.gbr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]
2022-12-13 as fabricated
    [fmcp_sma-B_CrtYd.gbr, fmcp_sma-B_Cu.gbr, fmcp_sma-B_Mask.gbr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]
2022-12-21 bom csv xml
    [fmcp_sma.csv, fmcp_sma.kicad_pcb, fmcp_sma.sch]
2023-01-03 update stackup
    [stackup.ods, stackup_alternatives.ods]
2023-01-03 add license
    [fmcp_sma.kicad_pcb, fmcp_sma.sch]
